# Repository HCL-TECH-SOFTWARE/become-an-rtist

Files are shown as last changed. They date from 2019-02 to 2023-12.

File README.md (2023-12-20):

# Become an RTist
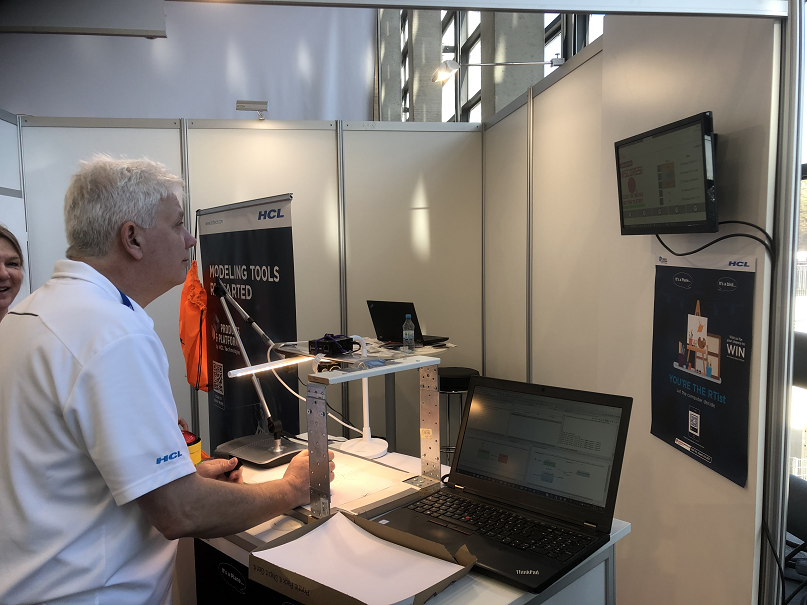
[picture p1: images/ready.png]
become an rtist Become An RTist


This is a sketch drawing game built with [DevOps Model RealTime](https://www.hcl-software.com/devops-model-realtime) (formerly known as HCL RTist). It is intended to run on a Raspberry Pi 3+ (or newer) equipped with a camera and a push button. In addition to the Model RealTime generated C++ application that runs on the Raspberry Pi, the system also consists of the following applications:
* An image recognizer Python script. It runs on the Raspberry Pi as an HTTP server to serve requests for image recognition.
* A web server implemented in Node JS. The C++ application communicates with it over HTTP. This web server can run on a different machine, for example a laptop that is connected to the same network as the Raspberry Pi.
* A web application implemented in JavaScript, HTML and CSS. This runs in a web browser on any computer.

For more information about the game set-up and how it works, see <a href="https://github.com/HCL-TECH-SOFTWARE/become-an-rtist/blob/master/BecomeAnRTist.pdf">these slides</a>. Also watch [this video](https://www.youtube.com/watch?v=UPmKu93ESZ8) to get an overview of the game and see it in action.

## Hardware setup
A bill of material can be found [here](BOM.md).
* Connect the camera to the Raspberry Pi and enable it in the Pi settings. 
* Connect the push button to the Raspberry Pi. Connect one wire to pin 6 (GND) and another to pin 12 (GPIO 18). It's not necessary to use resistors, but having them also won't hurt. 
* Make sure the Raspberry Pi is on the same network as the computer where the web server will run. For best performance, assign a static IP address to the Raspberry Pi and connect it directly to the computer with an ethernet cable. For example, follow these <a href="http://www.circuitbasics.com/how-to-connect-to-a-raspberry-pi-directly-with-an-ethernet-cable/">instructions</a>. Then update your hosts file (on both machines, including /etc/hosts on RPi) and assign the name "rtist-pi" to the IP address of the Raspberry Pi.
* Place the Raspberry Pi on a desk lamp, with the camera facing down.
* Calibrate the camera so that it can get a good shot of a regular A4 paper placed under the lamp. Start by installing some useful tools in the Pi by following these <a href="https://blog.miguelgrinberg.com/post/how-to-build-and-run-mjpg-streamer-on-the-raspberry-pi">instructions</a>.
  * Open a terminal and login to the Raspberry Pi. Perform these commands:
  
    `mkdir /tmp/stream`
    
    `raspistill --nopreview -w 640 -h 480 -q 5 -o /tmp/stream/pic.jpg -tl 100 -t 9999999 -th 0:0:0`
  * Open another terminal, login to the Pi and then perform this command:
  
    `LD_LIBRARY_PATH=/usr/local/lib mjpg_streamer -i "input_file.so -f /tmp/stream -n pic.jpg" -o "output_http.so -w /usr/local/www"`

  * Open [http://rtist-pi:8080/stream.html](http://rtist-pi:8080/stream.html) in a web browser to see a live stream from the camera.
    
    Move the paper under the lamp, and adjust the lamp height, until the paper is fully visible by the camera. Then mark the paper position, for example using a transparent tape.
    
* Initialize and test the push button by running the Python 2.7 script [button_test_2.py](image_recognition/button_test_2.py). There should be a printout each time the button is pushed.
    
## Set-up image recognition on the Raspberry Pi
* Install libraries required for Tensorflow

  ` sudo apt-get install libhdf5-dev`

* Install Tensorflow on the Raspberry Pi by following these [instructions](https://www.tensorflow.org/install/pip?lang=python2) (for Python 2.7).
* Open a terminal on the Raspberry Pi and perform the command 

  `source ~/venv/bin/activate`

* Copy the script [label_image_server.py](image_recognition/label_image_server.py) to the folder /become-an-rtist/image_recognition on the Pi. Also copy the trained Tensorflow model [output_graph.pb](image_recognition/output_graph.pb) and the list of words to recognize [output_labels.txt](image_recognition/output_labels.txt) to the same place. Then go into that folder and perform the command:

  `python label_image_server.py --graph=output_graph.pb --labels=output_labels.txt --input_layer=Placeholder --output_layer=final_result --input_height=224 --input_width=224`

The script now waits for incoming HTTP image recognition requests on port 5555.
    
## Build game application on a computer

### Install Required Software
1. [Model RealTime]([https://www.devops-community.com/realtime-software-tooling-rtist.html](https://www.hcl-software.com/devops-model-realtime))
2. **On Windows:** [Raspberry Pi cross-compiler](http://gnutoolchains.com/raspberry/)

Make sure that its **bin** folder (with make and g++) has been added to **PATH** variable.

### Prepare sources and build the application
1. The communication with the web server and the Python script uses the [lib-http-server](https://github.com/hcl-pnp-rtist/lib-http-server) library. Clone the project and import it to your workspace.

  `git clone https://github.com/HCL-TECH-SOFTWARE/lib-http-server.git`

2. [Paho-MQTT](https://www.eclipse.org/paho/downloads.php) 
    1. Get sources
    
    `git clone https://github.com/eclipse/paho.mqtt.c.git`
  
    2. Buld them or use [pre-built libs](libs/paho_mqtt_lib.zip) from this repo.
    3. Copy **libpaho-mqtt3c.so.1** to **/home/pi/become-an-rtist/** on the Raspberry Pi.
  
3. [POCO](https://pocoproject.org/)
    1. You must build the POCO shared libraries for the Raspberry Pi. This can either be done using cmake (see POCO documentation) or you can add the POCO sources to an Eclipse cross-compilation project and build them yourself. 
    2. Only **Foundation** and the **Net** libraries are used.    
    3. You may use the [Eclipse project](libs/poco_eclipse_projects.zip) from this repo to build libraries.
    4. Import it into your workspace, configure the path to the Raspberry cross-compiler in **project properties -> C/C++ Build -> Settings -> Cross Settings**,    
    5. Build the projects.
    6. Copy the shared libraries to **/home/pi/become-an-rtist/** on the Raspberry Pi.
    
4. [WiringPi](http://wiringpi.com/)
    1. You may use [eclipse project](libs/wiringPi.zip) from this repo to build the library.
    2. Import it into your workspace, configure the path to the Raspberry cross-compiler in **project properties -> C/C++ Build -> Settings -> Cross Settings, and build project.**
    3. Build it. It will be built into a static library, so you don't have to copy it to the Raspberry Pi.
    
5. Build the Model RealTime TargetRTS for Raspberry Pi
    1. Make a copy of any Linux TargetRTS
    2. In Model RealTime run **Target RTS Wizard** from the **TargetRTS** top menu.
    3. Select LinuxT.x64-gcc-12.x configuration and the **Duplicate** option from the **Manage** list.
    4. Under **Create New** check **Target Name** and **Libset Name**
    5. Click **Finish**
    6. For Windows you can use the file from this repo [libset.mk](libset.mk), copy it to **<ModelRealTime_Installation_DIR>\rsa_rt\C++\TargetRTS\libset\\<created_libset_name>\libset.mk** 
    7. Use **Target RTS Wizard again**, select newly created target and the **Build** option from the **Manage** list.
    8. Click **Finish** and ensure the TargetRTS is built successfully.

6. Update the TC **rtapp.tcjs** by doing the following.
    1. Set the property **tc.pocoLoc** to the location of the POCO library. If you imported **Poco_Net** and **Poco_Foundation** projects from this repository it would be the path to your Model RealTime workspace.
    2. If using **Poco_Net** and **Poco_Foundation** projects open **httpServerLib.tcjs** file in **LibHttpServer** project and modify **tc.inclusionPaths** property by replacing **Net** with **Poco_Net** and **Foundation** with **Poco_Foundation**
    3. Set **tc.taretConfiguration** with the name of Target you created in the previous step.
    4. Ensure **tc.targetServicesLibrary** is set to TargetRTS path. E.g. **<ModelRealTime_Installation_DIR>\rsa_rt\C++\TargetRTS**
    5. Update **tc.inclusionPaths** so it points to WiringPi and Paho MQTT sources.
    6. Update **tc.linkArguments** property to reference the build location of the **POCO**, **WiringPi**, and **PahoMQTT** binaries
    
7. Build the TC by right-clicking on it and selecting **Build...**.

## Starting the web server
1. Install [Nodejs](https://nodejs.org/en/download/)

2. Go to webapp folder

`cd webapp`

3. Get the dependencies

`npm install`

4. During each round of the game sample images of the same word are shown.
    1. For this to work download [image archive](https://drive.google.com/open?id=12CoTw4aE1OSRWp0qEgsdbgP0TNc_HVKW) (2.8 Gb)
    2. Extract the contents to some folder
    3. Edit **sample_images_dir** property in [appconfig.json](webapp/appconfig.json) to point to the folder where the images were extracted.

5. Start the application

`node app.js`

6. Open [http://localhost:5000/](http://localhost:5000/) in a web browser

## MQTT Setup
See [these instructions](MQTT.md) to add a game dashboard updated via MQTT.

## Start the game application
The easiest way to start the application on the Pi is to create a **C/C++ Remote Application** run configuration in Model RealTime.
* Make sure the project and executable are set correctly, e.g. to **IoTBecomeAnRTist_target** and **default\executable.EXE**
* Create a new ssh connection to Raspberry pi and specify the remote path to be **/home/pi/become-an-rtist/executable**
* In the **Commands to execute before application** section add the following

  `sudo -i`
  
  `export LD_LIBRARY_PATH=/home/pi/become-an-rtist`
 
 * In the **Arguments** tab add the following arguments
  
  `-webhost=192.168.137.1 -webport=5000 -propFile=/home/pi/become-an-rtist/game.properties`

Replace **webhost** with the IP address of the computer that runs the web server. Replace the propFile path with the path on the Pi where you have copied the file [game.properties](game.properties).

* To be able to attach the Model RealTime debugger to the application also add **obslisten** argument with a port number, e.g.

  `-obslisten=12345`

* Run the remote C/C++ application created

* If **obslisten** argument was specified, attach the Model RealTime debugger by right clicking on the **rtapp** transformation configuration and selecting **Debug As -> Remote realtime application (attach)** from the context menu. Specify the Raspberry Pi hostname and **obslisten** port number in the dialog. Resume the application after the Model RealTime debugger is attached.

* The web application will show the hiscore list, when the game is ready to play!

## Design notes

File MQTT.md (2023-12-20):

# MQTT Setup
To make the game really connected with [MQTT](http://mqtt.org/) follow the steps below.
## Install MQTT broker
Raspberry Pi running the game must be able to connect to MQTT broker. One of the options is to install and run [Mosquitto](https://mosquitto.org/download/) on the Pi itself.

## Configure game connection settings
Modify [game.properties](game.properties) file on Raspberry Pi by setting 
**MQTT**  to true and to **MQTT_URL** MQTT broker connection URL.

## Import Node-Red flows
1. Create a new Node-RED server in **Servers** view of Model RealTime or use an existing one.
2. Start the Node-RED server.
3. If not done previously, install [node-red-dashboard](https://flows.nodered.org/node/node-red-dashboard) by selecting **Manage palette** from the top menu. In **Install** tab find and install node-red-dashboard.
4. From the top menu pick **Import->Clipboard** and select [flows.json](node-red\flows.json) file to import.
5. Edit MQTT input node by editing MQTT server connection.
6. Deploy the flows.
7. Open game dashboard by navigating to <NODE_RED_SERVER_URL>/ui, e.g. [http://localhost:1880/ui](http://localhost:1880/ui).

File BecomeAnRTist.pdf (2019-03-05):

# Become An RTist

IoT & Edge Computing Demo Application for HCL Rtist

### A Sketch Drawing Game (inspired by Google QuickDraw) (https://quickdraw.withgoogle.com/)

- The player gets a random word (e.g. car, horse, house...)
- He or she now has to draw the word on a paper in at most 20 sec.
- If the drawing is ready before 20 sec the player hits a big GO button
- When the GO button has been pressed, a camera takes a picture of the drawing
- The RTist application now analyzes the picture and tries to guess what the player has drawn
- If it cannot guess correctly, and time is up, the game is over. Otherwise it just tells the user it cannot guess the word, and he can modify the drawing and then press the GO button again.
- If the RTist app can guess the word, the player score increases (higher score the less time spent drawing, and also the more certain the image recognition was). The player then gets another word to guess.
- When the game is over, the player’s score is compared with a high score list. If the score qualifies for the high score list, the player is asked to write his name on the sketch and press the GO button again. A photo of the sketch is taken and stored in the high score list together with the date and score.

# ”Become an rtist” game

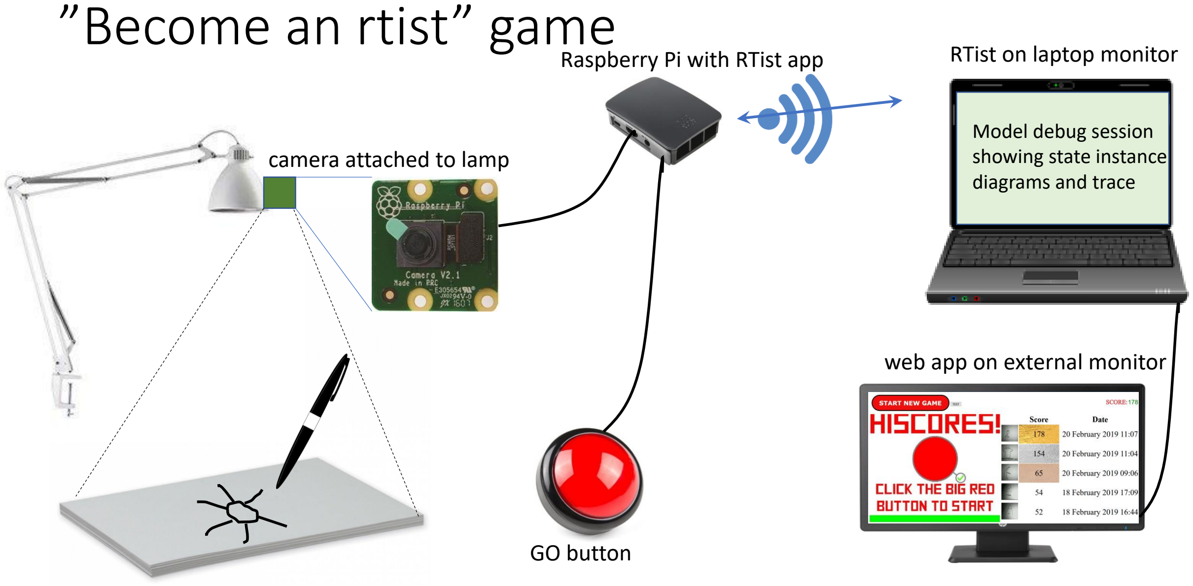
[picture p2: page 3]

camera attached to lamp

Raspberry Pi with RTist app

GO button

SUN

web app on external monitor

RTist on laptop monitor

Model debug session
showing state instance
diagrams and trace

# How does it work?

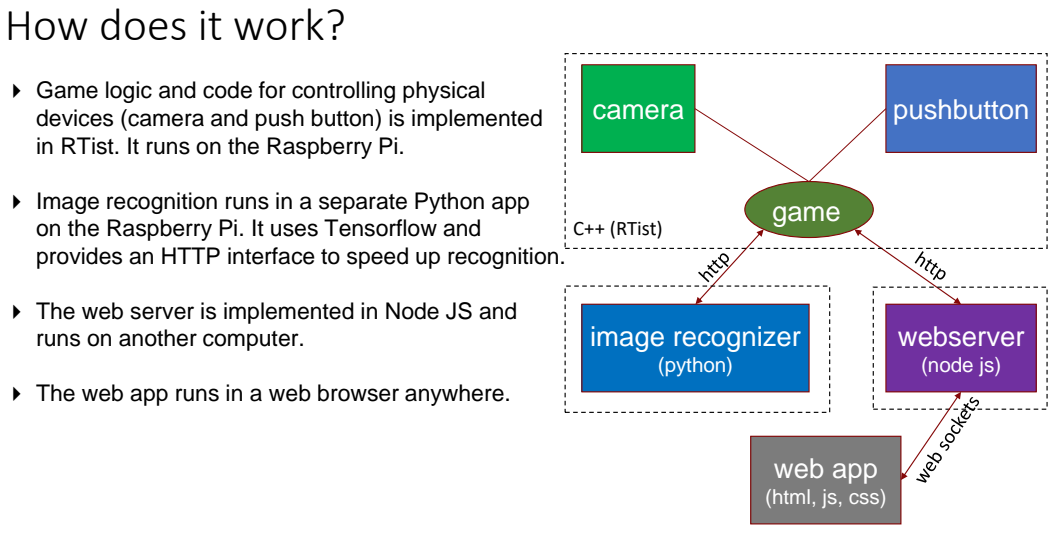
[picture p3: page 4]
camera; pushbutton; webserver; (node js); image recognizer; (python); game C++ (RTist)

Game logic and code for controlling physical
devices (camera and push button) is implemented
in RTist. It runs on the Raspberry Pi.

Image recognition runs in a separate Python app
on the Raspberry Pi. It uses Tensorflow and
provides an HTTP interface to speed up recognition.

The web server is implemented in Node JS and
runs on another computer.

The web app runs in a web browser anywhere.

web app
(html, js, css)

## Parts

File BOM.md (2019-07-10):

# Bill of Material
You need some hardware to build the BecomeAnRTist game.

* __Raspberry Pi 3 B+ (or newer) Premium Kit__ (approx cost 90 USD)

This means the Raspberry Pi itself as well as necessary accessories such as the plastic case cover, power supply, HDMI cable, 16 GB Micro-SD card with Raspbian OS installed.

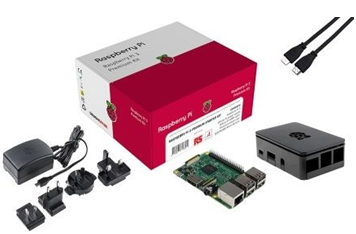
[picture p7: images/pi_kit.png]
pi kit Raspberry Pi 3 B+ Premium Kit


* __Short ethernet cable__ (approx cost 2 USD)

* __Pi Camera V2 Daylight__ (approx cost 30 USD)

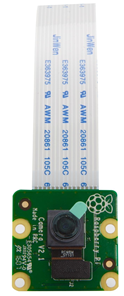
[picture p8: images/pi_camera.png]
pi camera Pi Camera V2 Daylight


* __Big red push button__ (approx cost 10 USD)

For example: Adafruit Massive Arcade Button with LED

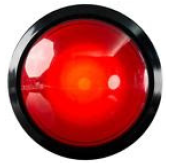
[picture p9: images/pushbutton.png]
push button Big red push button


* __Camera case__ (approx cost 15 USD)

It's good if it allows you to adjust the camera angle. For example: Cookie wheel camera case

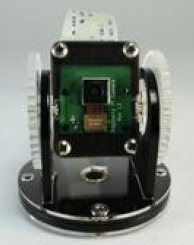
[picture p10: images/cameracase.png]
camera case Cookie wheel camera case


As an alternative, you can choose to mount the camera directly under the lamp, so you can adjust the camera by adjusting the lamp itself. In this case you can buy a longer camera cable so you can have the Pi on the table and the camera under the lamp.

* __Resistors and wires for connecting things together__ (approx cost 15 USD)

For example: The PiHut Ultimate Resistor Kit

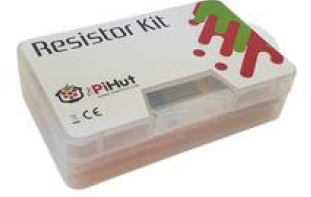
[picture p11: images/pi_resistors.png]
resistors Resistors


You may use a resistor when connecting the push button to the Pi, but it is strictly not necessary, so consider this an optional buy.

* __Arcade Button Quick-Connect Wire Pairs - 0.11" (10 pack)

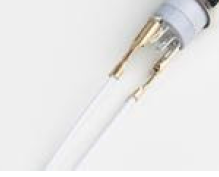
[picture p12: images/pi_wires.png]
wires Wires


These wires are for connecting the push button to the Pi. Which wires to use depend on the button.

* __LED desk lamp with good bright light__ (approx cost 50 USD)

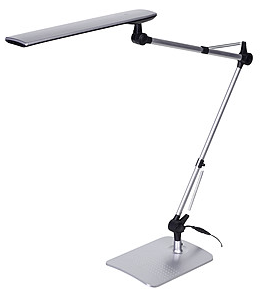
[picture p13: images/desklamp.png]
lamp Desk lamp


It's good if the lamp is stable enough so it can carry both the Pi and the camera. Alternatively, keep the Pi on the table and just attach the camera on the lamp since it is considerably lighter. In this case you need a longer than default camera cable. If you choose to attach the Pi on the lamp you may need a scaffolding to make the construction stable enough.

* __Paper and marker pen__ (approx cost 20 USD)

Ordinary printer paper will work (although expect to use a lot since a sketch usually "bleeds" through on the opposite side of the paper). Use a black marker pen with a 1-3 mm head.
As an alternative you can use a white board with white board pens and an eraser. We have tested this and it works, but you need to make sure it's not giving too much reflections since that could cause image recognition to fail.

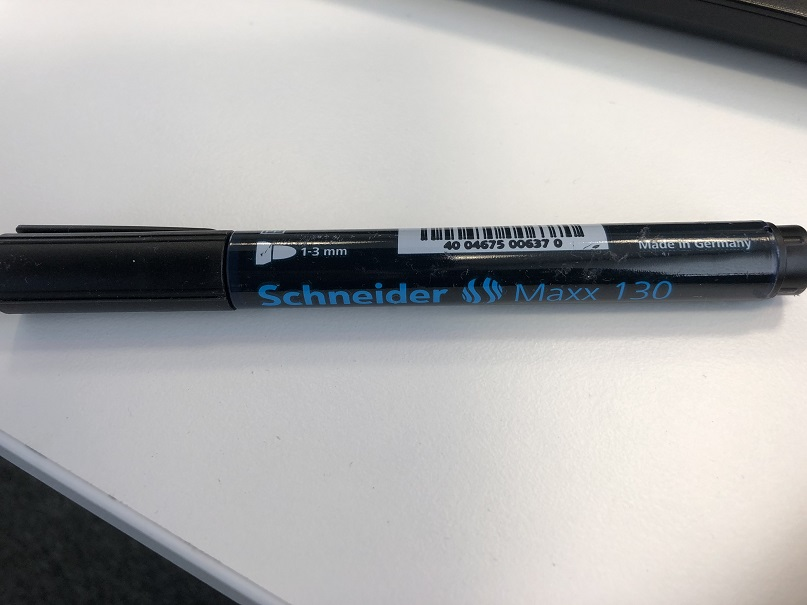
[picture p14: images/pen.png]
pen Marker pen


* __Material for building a scaffolding__ (approx cost 20 USD)

The purpose of the scaffolding is to make the construction stable enough so the lamp won't fall down. Depending on the lamp you use you may or may not need it. If you choose to have a scaffolding, its base can be a wooden or plastic tray with attached metal plates (those used when building walls in houses). They are strong and have pre-drilled holes where M5 screws will fit. It's good to cover the tray with for example a white paper, and use duct tape for marking on it the anticipated position of the paper.

scaffolding Scaffolding

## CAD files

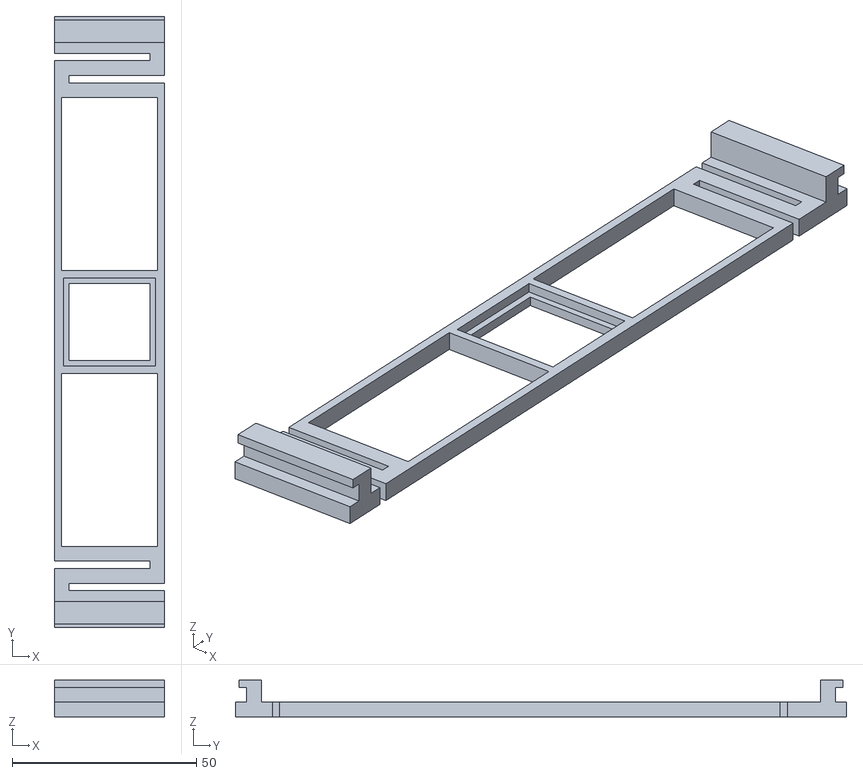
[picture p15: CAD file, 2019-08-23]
3d_models/camera_holder.stl
30.0 x 166.0 x 10.0

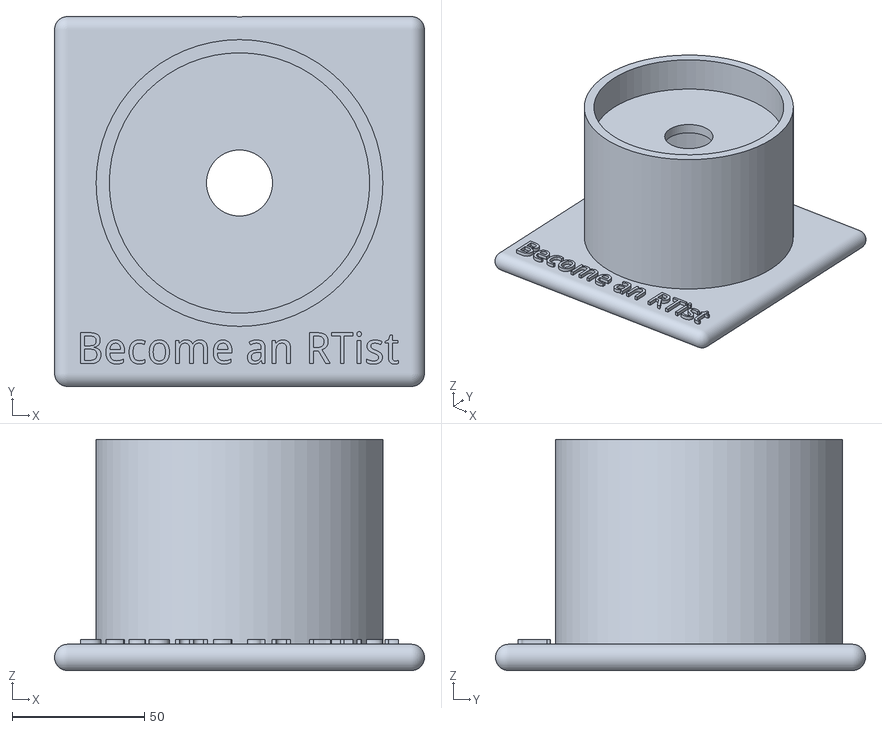
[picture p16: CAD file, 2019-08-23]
3d_models/mattias_button_1.stl
140.0 x 140.0 x 87.5

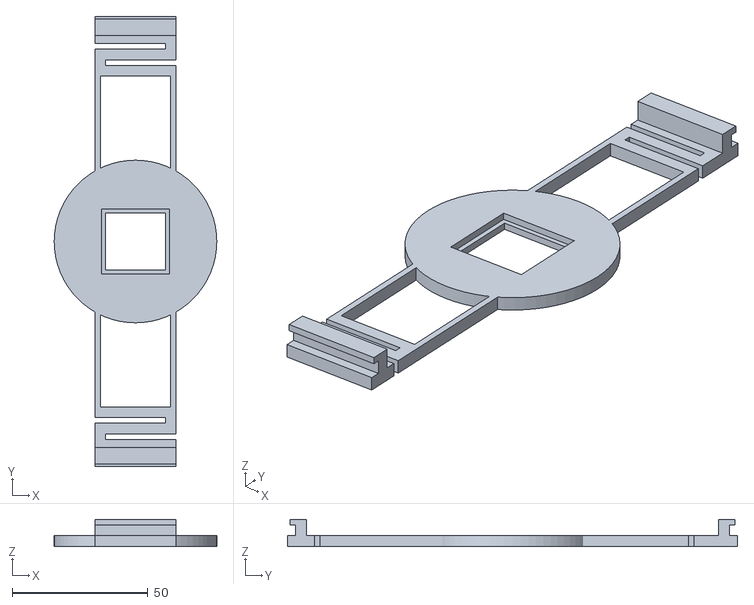
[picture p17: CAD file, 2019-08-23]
3d_models/camera_holder_2.stl
60.0 x 166.0 x 10.0

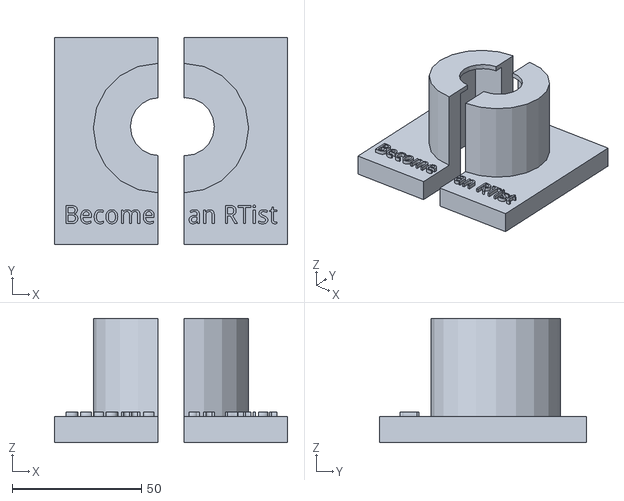
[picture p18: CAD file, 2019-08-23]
3d_models/button_case_3.stl
90.0 x 80.0 x 48.0

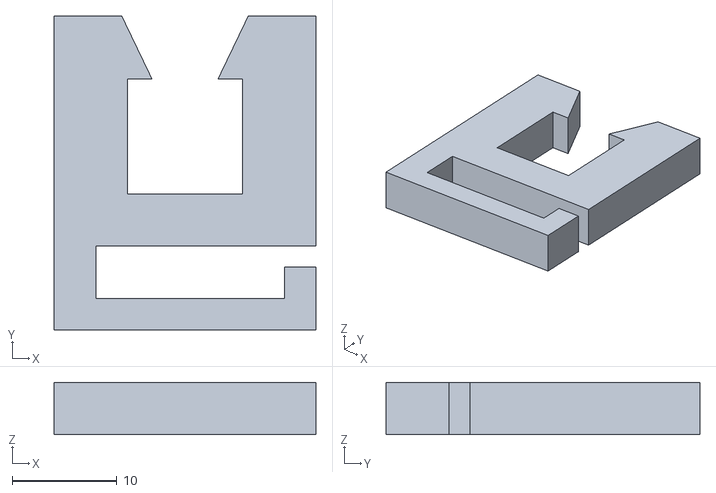
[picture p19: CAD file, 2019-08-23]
3d_models/wire_support.stl
25.0 x 30.0 x 5.00

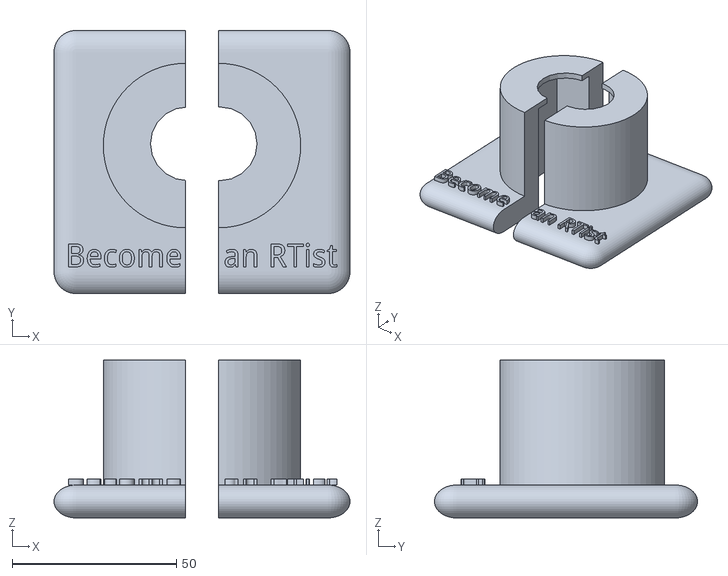
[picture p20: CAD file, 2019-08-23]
3d_models/button_case_4.stl
90.0 x 80.0 x 48.0

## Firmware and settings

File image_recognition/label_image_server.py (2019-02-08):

##############################################################################
# HTTP server serving image recognition requests
#
# (c) Copyright HCL Technologies Ltd. 2019.  MIT Licensed!
#
##############################################################################

from __future__ import absolute_import
from __future__ import division
from __future__ import print_function

import argparse

import numpy as np
import tensorflow as tf

# HTTP server
from BaseHTTPServer import BaseHTTPRequestHandler, HTTPServer
#from http.server import BaseHTTPRequestHandler, HTTPServer (Python 3)
import time

class S(BaseHTTPRequestHandler):
    def _set_headers(self):
        self.send_response(200)
        self.send_header('Content-type', 'text/plain')
        self.end_headers()

    def do_GET(self):
        self._set_headers()
        if (self.path.startswith("/image_recognition")):
            start = time.time()
            file = self.path[24:]
              
            t = read_tensor_from_image_file(file, input_height=input_height, input_width=input_width, input_mean=input_mean, input_std=input_std)
            input_name = "import/" + input_layer
            output_name = "import/" + output_layer
            input_operation = self.graph.get_operation_by_name(input_name)
            output_operation = self.graph.get_operation_by_name(output_name)

            with tf.Session(graph=self.graph) as sess:
                results = sess.run(output_operation.outputs[0], {
                    input_operation.outputs[0]: t
                })
            results = np.squeeze(results)

            top_k = results.argsort()[-5:][::-1]
            end = time.time()
            # Build JSON response
            self.wfile.write("{\"" + self.labels[top_k[0]] + "\" : " + str(results[top_k[0]]) + ",")
            self.wfile.write("\"" + self.labels[top_k[1]] + "\" : " + str(results[top_k[1]]) + ",")
            self.wfile.write("\"" + self.labels[top_k[2]] + "\" : " + str(results[top_k[2]]) + ",")
            self.wfile.write("\"" + self.labels[top_k[3]] + "\" : " + str(results[top_k[3]]) + ",")
            self.wfile.write("\"" + self.labels[top_k[4]] + "\" : " + str(results[top_k[4]]) + ",")
            self.wfile.write("\"timeSpent\" : " + str(end - start) + "}")
        else:
#            self.wfile.write("Unknown request".encode("utf-8"))
             self.wfile.write("Unknown request")


    def do_HEAD(self):
        self._set_headers()

def runServer(graph, labels, server_class=HTTPServer, handler_class=S, port=5555):
    server_address = ('', port)
    handler_class.graph = graph
    handler_class.labels = labels
    server = server_class(server_address, handler_class)
    print('Starting HTTP server...')
    server.serve_forever()

def load_graph(model_file):
  graph = tf.Graph()
  graph_def = tf.GraphDef()

  with open(model_file, "rb") as f:
    graph_def.ParseFromString(f.read())
  with graph.as_default():
    tf.import_graph_def(graph_def)

  return graph


def read_tensor_from_image_file(file_name,
                                input_height=299,
                                input_width=299,
                                input_mean=0,
                                input_std=255):
  input_name = "file_reader"
  output_name = "normalized"
  file_reader = tf.read_file(file_name, input_name)
  if file_name.endswith(".png"):
    image_reader = tf.image.decode_png(
        file_reader, channels=3, name="png_reader")
  elif file_name.endswith(".gif"):
    image_reader = tf.squeeze(
        tf.image.decode_gif(file_reader, name="gif_reader"))
  elif file_name.endswith(".bmp"):
    image_reader = tf.image.decode_bmp(file_reader, name="bmp_reader")
  else:
    image_reader = tf.image.decode_jpeg(
        file_reader, channels=3, name="jpeg_reader")
  float_caster = tf.cast(image_reader, tf.float32)
  dims_expander = tf.expand_dims(float_caster, 0)
  resized = tf.image.resize_bilinear(dims_expander, [input_height, input_width])
  normalized = tf.divide(tf.subtract(resized, [input_mean]), [input_std])
  sess = tf.Session()
  result = sess.run(normalized)

  return result


def load_labels(label_file):
  label = []
  proto_as_ascii_lines = tf.gfile.GFile(label_file).readlines()
  for l in proto_as_ascii_lines:
    label.append(l.rstrip())
  return label


if __name__ == "__main__":
  file_name = "tensorflow/examples/label_image/data/grace_hopper.jpg"
  model_file = \
    "tensorflow/examples/label_image/data/inception_v3_2016_08_28_frozen.pb"
  label_file = "tensorflow/examples/label_image/data/imagenet_slim_labels.txt"
  input_height = 299
  input_width = 299
  input_mean = 0
  input_std = 255
  input_layer = "input"
  output_layer = "InceptionV3/Predictions/Reshape_1"

  parser = argparse.ArgumentParser()
  parser.add_argument("--image", help="image to be processed")
  parser.add_argument("--graph", help="graph/model to be executed")
  parser.add_argument("--labels", help="name of file containing labels")
  parser.add_argument("--input_height", type=int, help="input height")
  parser.add_argument("--input_width", type=int, help="input width")
  parser.add_argument("--input_mean", type=int, help="input mean")
  parser.add_argument("--input_std", type=int, help="input std")
  parser.add_argument("--input_layer", help="name of input layer")
  parser.add_argument("--output_layer", help="name of output layer")
  args = parser.parse_args()

  if args.graph:
    model_file = args.graph
  if args.image:
    file_name = args.image
  if args.labels:
    label_file = args.labels
  if args.input_height:
    input_height = args.input_height
  if args.input_width:
    input_width = args.input_width
  if args.input_mean:
    input_mean = args.input_mean
  if args.input_std:
    input_std = args.input_std
  if args.input_layer:
    input_layer = args.input_layer
  if args.output_layer:
    output_layer = args.output_layer

  graph = load_graph(model_file)
  labels = load_labels(label_file)

  # Start HTTP server
  runServer(graph, labels)

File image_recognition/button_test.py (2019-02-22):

import RPi.GPIO as GPIO # Import Raspberry Pi GPIO library
GPIO.setwarnings(False) # Ignore warning for now
GPIO.setmode(GPIO.BOARD) # Use physical pin numbering
GPIO.setup(10, GPIO.IN, pull_up_down=GPIO.PUD_DOWN) # Set pin 10 to be an input pin and set initial value to be pulled low (off)

while True: # Run forever
	if GPIO.input(10) == GPIO.HIGH:
		print("Button was pushed!")
		

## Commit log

2019-01-30 Add 20 second timer while drawing and Game Over in case of timeout.
2019-02-22 Various fixes for Embedded World conference
    [button_test.py]
2019-03-04 Track all game plays in JSON file
2019-03-28 Pictures for the BOM
2019-03-28 Images in the BOM
2019-03-28 Fixes for images in BOM
2019-03-28 More BOM updates
2019-04-26 Change button connection scheme and flip camera picture due to another camera position
2019-04-26 python script for another button connection scheme
2019-06-04 Replace initial transition with transition from entry point
    in DrawingWord state. Prevents deadlock in case we get a "GameOver"
    while an image is being analyzed. The next time DrawingWord is entered
    we should go to WaitForDrawing and not back to AnalyzeDrawing.
2019-06-04 #5 game.properties sample
2019-06-19 #5 save node-red flow handling game MQTT
2019-08-23 Add various related 3d models
    [button_case_3.stl, button_case_4.stl, camera_holder.stl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]
2019-09-10 #7 Send `buttonPushed()` signal with higher priority.
2019-09-12 Improved UI dashboard in node-red flows
2019-11-08 Fix to detect (and prevent) fake button pushes
2019-11-08 Splitted node red flow into seprate ones for simplicity
2020-01-13 #11 change camera name format
